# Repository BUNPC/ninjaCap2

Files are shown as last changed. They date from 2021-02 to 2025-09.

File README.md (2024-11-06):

# ninjaCap2 Repo: BRIEF DESCRIPTION
This repository contains the complete framework necessary to generate ninjaCaps. 
This help file explains how to set up and run the ninjacap code using matlab and the blender-python integration. 
Last major version: Feb 2021.

Inputs to this framework are
1. a "probe.SD" file that describes the geometrical setup (as documented in the Homer3 / AtlasViewer toolbox)
1. the desired headcircumference in cm.

Outputs of this code are four .stl files for 3D printing with ninjaflex.

# HOW TO SET EVERYTHING UP

## 1. Install Matlab and the AtlasViewer (Homer3) toolbox for Matlab
The latest Matlab version that the ninjaCap code was successfully tested with is R2019b.
Install the latest version of AtlasViewer and Homer3 (sourcecode, not the executable) for Matlab. You can get them here:	https://github.com/BUNPC/AtlasViewer
https://github.com/BUNPC/Homer3
Don't forget to install the toolbox by running "setpaths" (see AtlasViewer/Homer3 documentation).

## 2. Get the latest version of ninjaCap2 code
you are already here: make a local copy of this repository (https://github.com/neuluce/ninjaCap2).

## 3. Install Blender 2.82 64Bit 
Please note that the ninjacap2 python script may or may not be compatible with older/other versions, 
as blender python commands might be subject to changes over time.
You can get it here:		https://www.blender.org/download/releases/2-82/

## 4. Add necessary Python modules to Blender's Python
Blender uses its own Python. Blender 2.80 upwards uses Python 3.7.
For this reason, you need to install necessary modules (scipy) explicitly into Blender's Python.
If you have your own Python distribution + modules such as Anaconda installed,
blender's Python will not natively find those modules. 
If you manage modules with pip, make sure they are installed into Blender's Python!
In the instructions below, < > defines commands to run in the console and
paths are example paths that need to be adapted to the directories in your installation.
1. Start your Python CMD shell (e.g. Anaconda Prompt) or the Windows CMD console as *administrator*
1. move to the blender\python folder, (e.g. C:\Program Files\Blender Foundation\Blender\2.82\python\bin)
1. from this folder, run *<python -m ensurepip>*. This will link and install pip for python module management. Please note that Blender 2.81 and following versions might not need you to run the ensurepip command. If you get an error when running this command in version(s) 2.81+ just skip this step.
1. update pip and pip wheel by running *<python -m pip install --upgrade pip>* and
	*<python -m pip install --upgrade pip setuptools wheel>*
1. install the **scipy module** using pip. specify the target folder (--target), otherwise the modules might end up in your
	OS python folders and will not be found by Blender. E.g. *<	python -m pip install scipy --target="C:\Program Files\Blender Foundation\Blender\2.80\python\lib">* 
  (adapt directory to your folder structure accordingly).

# PREPARING FILES FOR A CAP BUILD

## 1. Create your "probe.SD" using the newest AtlasViewer GUI. 
Follow the typical process to generate a probe with the AtlasViewer SDgui. Then, for each source, detector AND dummy optode, select the Grommet Type of that optode. The Grommet Type is an identifier that is used in the cap generation to place the desired element (holder, grommet, …) at the position of the corresponding optode. A brief instruction and list of currently supported grommets/holders, including their IDs, is provided [here](https://github.com/neuluce/ninjaCap/blob/master/docu/grommet_lookup.pdf). Selecting the type “#NONE” will skip the placement of a holder/ an element for this optode. You can assign any Grommet Type identifier to any optode (source, detector, and dummy optodes)!

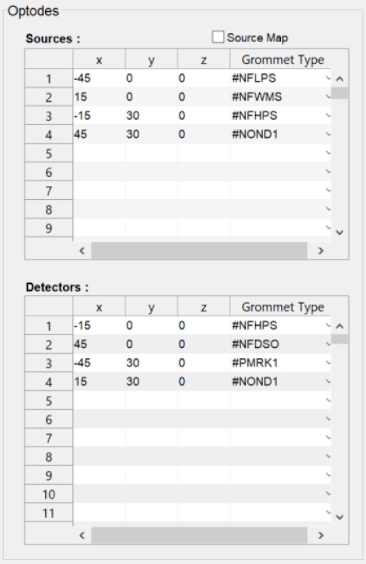
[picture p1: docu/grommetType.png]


Please note for Short Separation (SS) channels: Depending on the type of grommet you choose, short separation channels (holes for a SS fiber) are typically already included. In your SD probe layout, you might have added dedicated SS optodes. If you did, just give those a “#NONE” ID to skip the placement of a dedicated element at the SS optode location.

Please make sure you follow the keep out guidelines shown [here](https://github.com/neuluce/ninjaCap/blob/master/docu/guidelines_keepOutRegions): If you place grommets in the keep out region, they will overlap with the ear slits.
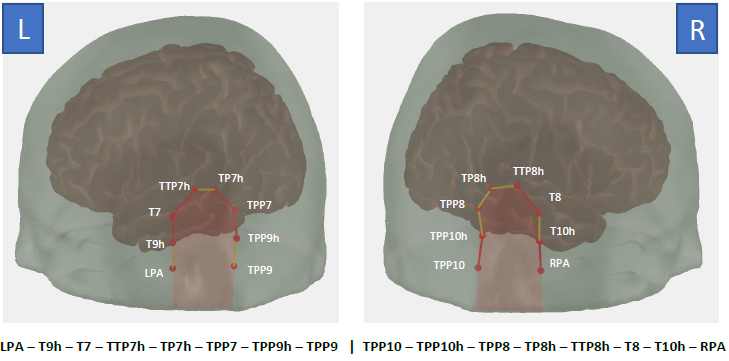
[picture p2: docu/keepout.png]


# HOW TO BUILD A CAP 

## 1. Provide all relevant files:
1. place the "probe.SD" file in a new directory.
1. the following **optional** steps are available, but are not necessary by default:
    1. (optional) provide your own 'atlasViewer.mat' headmodel in the root '.../ninjaCap/' directory
    1. (optional) provide your custom side outline .svg file in the '.../ninjaCap/svg/' directory. -> change the filename in 'ninjaCap/matfun/cap.m' accordingly, if you did not use the default names 'side_piece1.svg' and 'side_piece2.svg'.
    1. (optional, advanced) provide your custom .STL elements to be placed with corresponding grommet IDs. These elements can be grommets, straps, cases, anything. Place them in '.../ninjaCap/stl/elements/<identifier>/'. For this to work, you need to follow the ID-/file-/folder- naming conventions outlined [here](https://github.com/neuluce/ninjaCap/blob/master/docu/grommet_lookup.pdf).
	
## 2. Generate the ninjaCap 
1. Open matlab, go to AtlasViewer directory and add AtlasViewer directory to matlab path by running the command 'setpaths' in the matlab command line. 

2. Go to ninjaCap2 directory and add ninjaCap2 directory to matlab path by running the command 'addpath(genpath('.'))' in the matlab command line.

3. Now go to the "probe.SD" directory and run the function '* generateNinjaCap.m*'. The only argument for this function is the desired head circumference in cm. To generate a cap with 56cm headcircumference, run ' generateNinjaCap(56)'. If you do not provide an argument, 56cm is assumed per default. Watch your cap being built. By the end of the process, matlab open a Blender3D workspace.

4. In the Blender workspace, the python script 'nynja_blender_exec.py' (ninjaCap root directory) should already be loaded per default on the right hand side. If for any case it isnt or you have your own Blender workspace, open the script window and load the script. Run the script by pressing ALT+P or clicking on 'Text -> Run Script' in the script window.

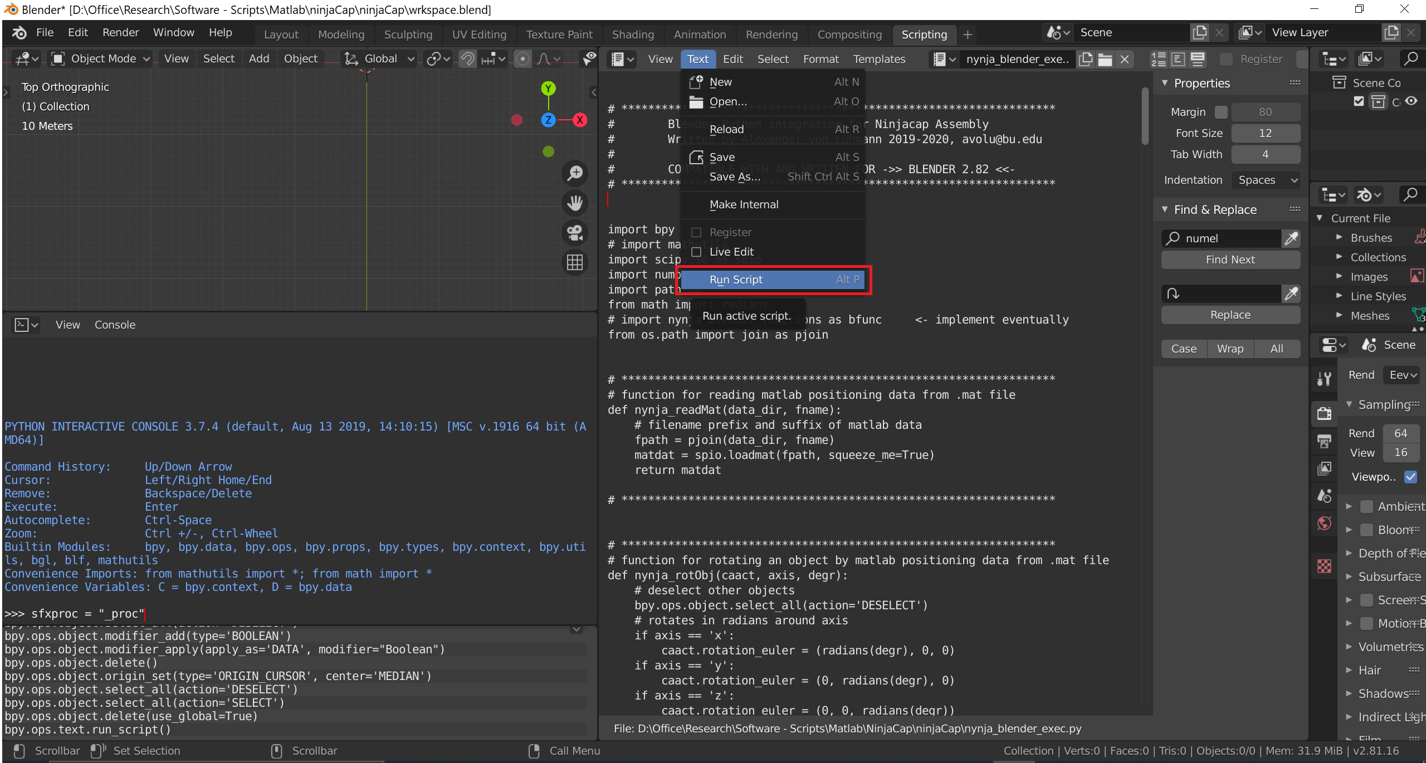
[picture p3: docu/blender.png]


When blender has done its work, close it. This will also terminate the running matlab script.

## 3. Get and print the ninjaCap files
The fully generated and assembled ninjaCap panels are saved in the '.../ninjaCap2/print/' subdirectory.
You should find four .STL files there: 'sideLeft_proc.STL', 'sideRight_proc.STL', 'top1_proc.STL' and 'top2_proc_STL'.
These files can now be 3D printed. For this, use ninjaflex material with the CURA LulzBot Taz 6 Aerostruder and the printing profile 'ninjaCap_profile.curaprofile' that is also provided in the '.../ninjaCap2/print/' subdirectory.
If you want to view the files before moving on to the 3D printing step, you can open them with any STL viewer, such as for example [Meshlab](https://sourceforge.net/projects/meshlab/).

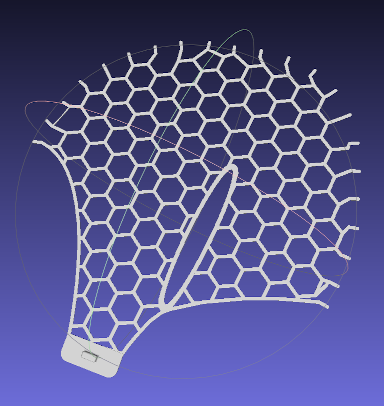
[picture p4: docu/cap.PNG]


## 4. Finish the cap
With all the panels printed, you now need to assemble the cap, e.g. with an ultrasonic welder. Done.

# DIRECTORY AND FILE STRUCTURE
The ninjaCap2 repository has all main scripts and workspaces that need to be executed in the root directory. The subdirectories provide documentation, auxiliary functions, templates, user inputs, generated files, and so forth. This structure is documented in the following:

* /docu/ - contains images and grommet ID manual and documentation
* /extfun/ - contains external matlab scripts, e.g. from matlab central, including the corresponding license files
* /fw/ - a default AtlasViewer directory (**ignore**)
* /imagerecon/ - a default AtlasViewer directory (**ignore**)
* /scripts/ - contains all ninjaCapw matlab scripts and functions called by 'generateNinjaCap.m' and its subroutines.
* /print/ - contains the results of the ninjaCap generation process. You find your .STL files for 3D printing, and the 3D printing profile in here.
* /stl/ - contains (subfolders with) the cap elements that are generated by the matlab routines, as well as element templates (grommets, chinstraps, etc..). The Blender Python script assembles the cap using these elements.
* /svg/ - contains .svg files for the outline of the sidepieces. 
* /template/ - contains templates for the projection of 3D AtlasViewer probe coordinates relative to the EEG 10-10 system onto 2D cap panels.
* / - contains the necessary files for cap generation that the user needs to provide: 'probe.SD'.

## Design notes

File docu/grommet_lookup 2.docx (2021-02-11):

# Preparing files for a ninjaCap build

Inputs to our ninjaCap framework are

1. a "probe.SD" file that describes the geometrical setup (as documented in the Homer2 toolbox) and the grommet types to be used. NOTE: For this you need the latest version of the AtlasViewer GUI (May 2020 or newer)
2. the desired headcircumference in cm.

Outputs of this code are four .stl files for 3D printing with ninjaflex.

## Create your "probe.SD" using the the SDgui of the latest version of AtlasViewer (May 2020 or newer) that you can find here:

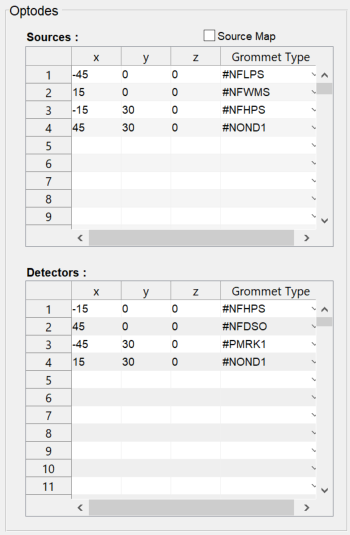
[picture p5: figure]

https://github.com/BUNPC/AtlasViewer

For each source, detector AND dummy optode, select the Grommet Type of that optode. The Grommet Type is an identifier that is used in the cap generation to place the desired element (holder, grommet, …) at the position of the corresponding optode. The available types of grommets and their corresponding identifiers are given in the table on the next page. Selecting the type “#NONE” will skip the placement of an element for this optode. You can assign any Grommet Type identifier to any optode (source, detector, and dummy optodes)!

Please note for Short Separation (SS) Measurements: Depending on the type of grommet you choose, short separation channels (holes for a SS fiber) are typically already included. In your SD probe layout, you might have added dedicated SS optodes. If you did, just give those a “#NONE” ID to skip the placement of a dedicated element at the SS optode location.

Save that configuration under the name "probe" with the native ".SD" file extension under …\ninjaCap\userinput\probe.SD.

If you want to add your own (custom) Grommet Type:

STL files for these elements are placed under
…/ninjaCap/stl/elements/<identifier>/…

where <identifier> is the folder name identical to the defined string ID. Files within are always “grommet.stl” and “grommetComplement.stl”, where “grommet” is the element to be placed, and “grommetComplement” is the keep out geometry used to create corresponding holes/spaces in the panel grids. This compliment must be the same size as the needed gap in the pattern of the panel grids for the hole produced by the grommet. These “grommets” can have any geometry and can also be elements that are not “grommets” after all. If your grommet ID is not available in AtlasViewer, you can select any type and manually change them to your new custom ID by manually opening the SD file in matlab and changing the entries in the following three fields of SD struct: ‘SrcGrommetType’, ‘DetGrommetType’ and ‘DummyGrommetType’. When saving the STL for a new grommet you must ensure that the grommet is aligned on the X-Y plane as it’s bottom and the origin point for both the grommet and the compliment must be in the center of their hole for the optode to ensure correct grommet placement on the ninjaCap.

Identifier | Info | Image | Dimensions

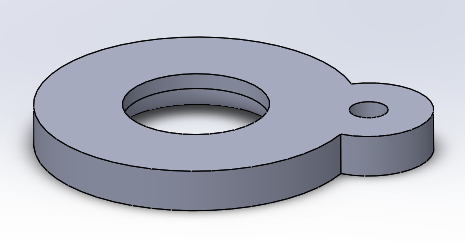
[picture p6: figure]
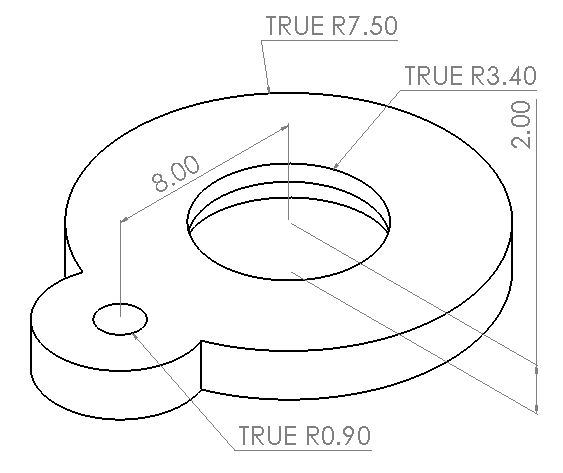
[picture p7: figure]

#NFLPS | NIRS: Fiber-based optode holder (CW6 fibers) with Low Profile and single Short-separation hole

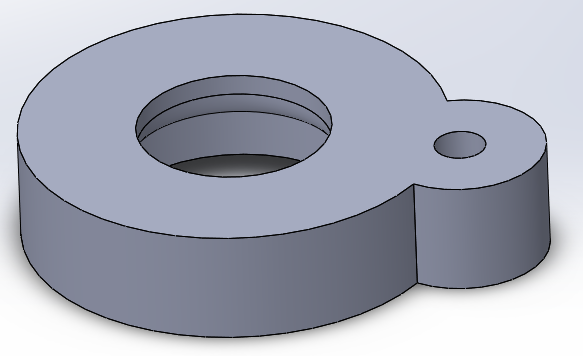
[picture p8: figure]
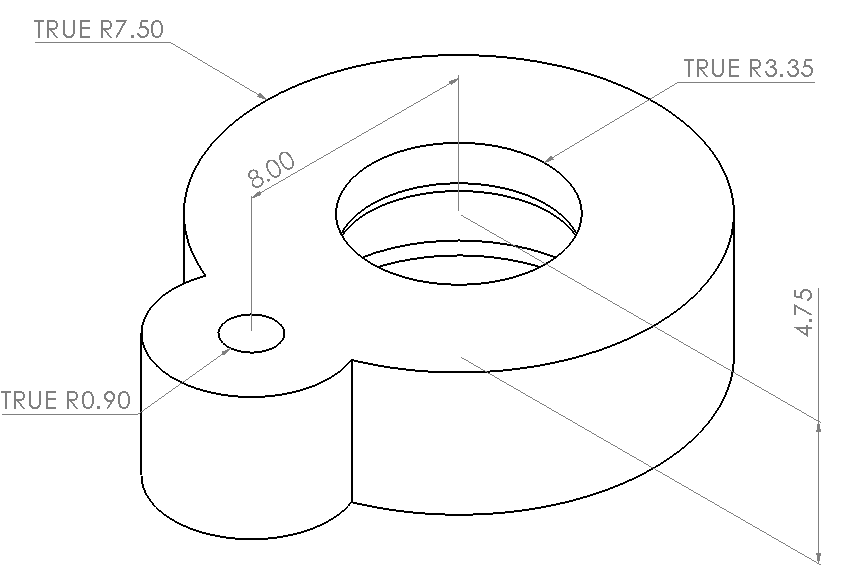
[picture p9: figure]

#NFHPS | NIRS: Fiber-based optode holder (CW6 fibers) with High Profile and single Short-separation hole

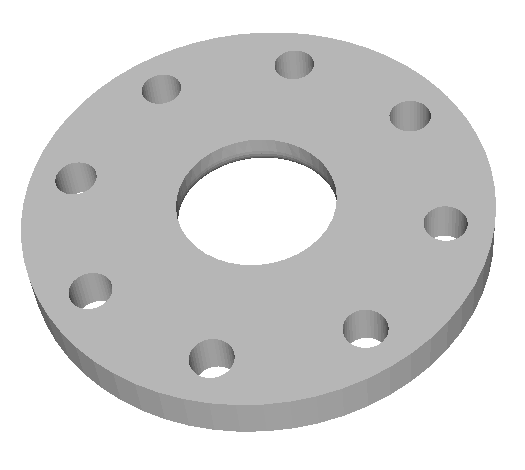
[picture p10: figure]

#NFWMS | NIRS: Fiber-based Wide optode holder (CW6 fibers) with Multiple Short-separation holes | | Inner radius: 03.4 mm Outer radius: 08.0 mm Height: 02.0 mm SS Distance: 08.0 mm SS radius: 0.90 mm

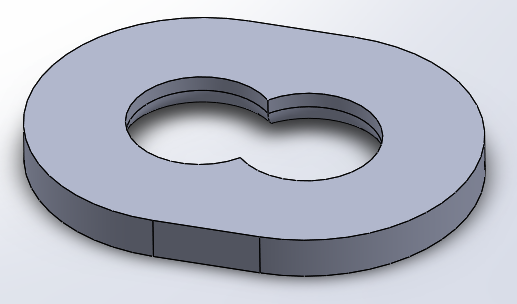
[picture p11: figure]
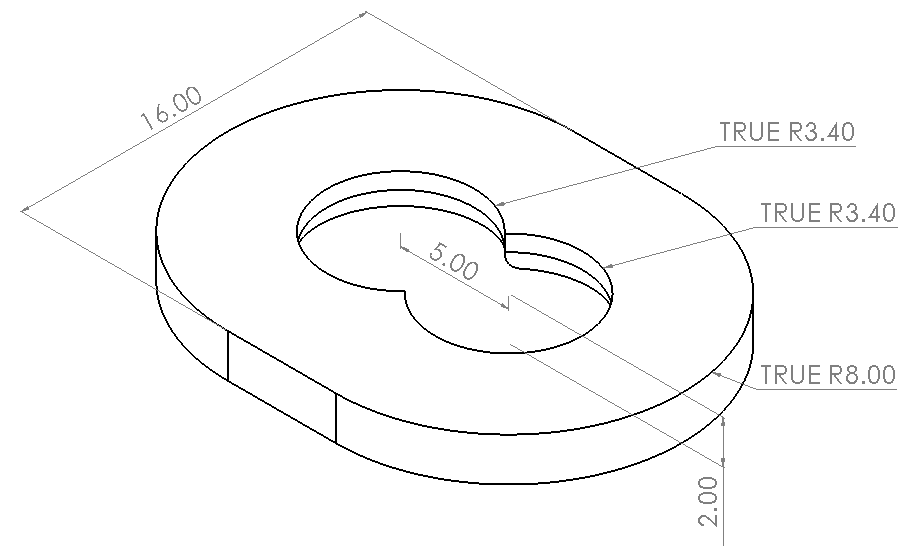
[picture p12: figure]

#NFDSO | NIRS: Fiber-based Dual Ss Optode holder

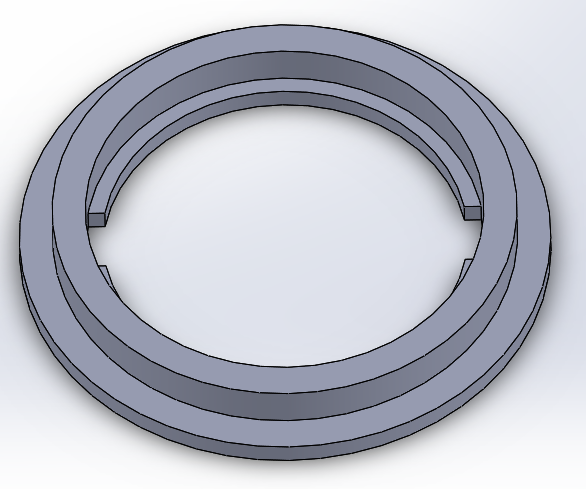
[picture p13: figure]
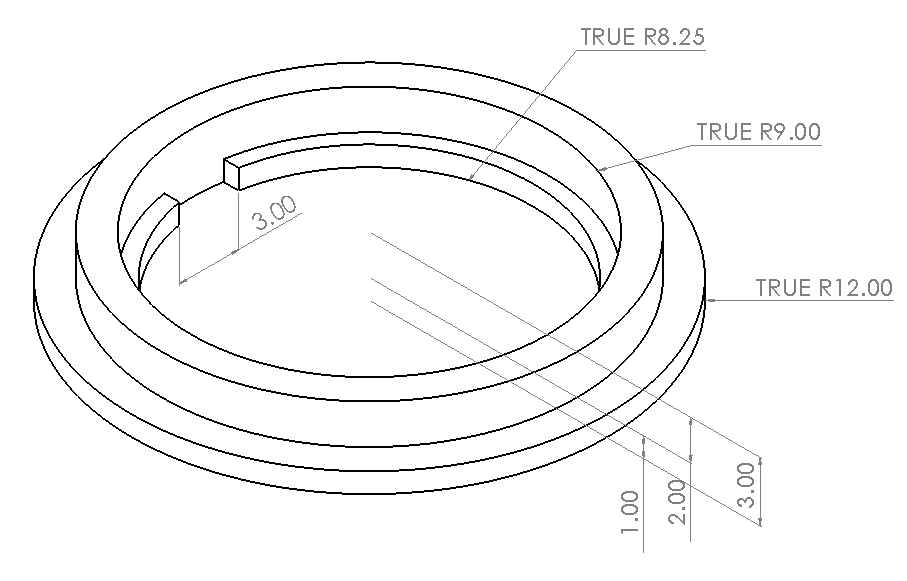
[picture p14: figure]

#NOND1 | NIRS: Open fNIRS Dual optode holder for optodes in printed case

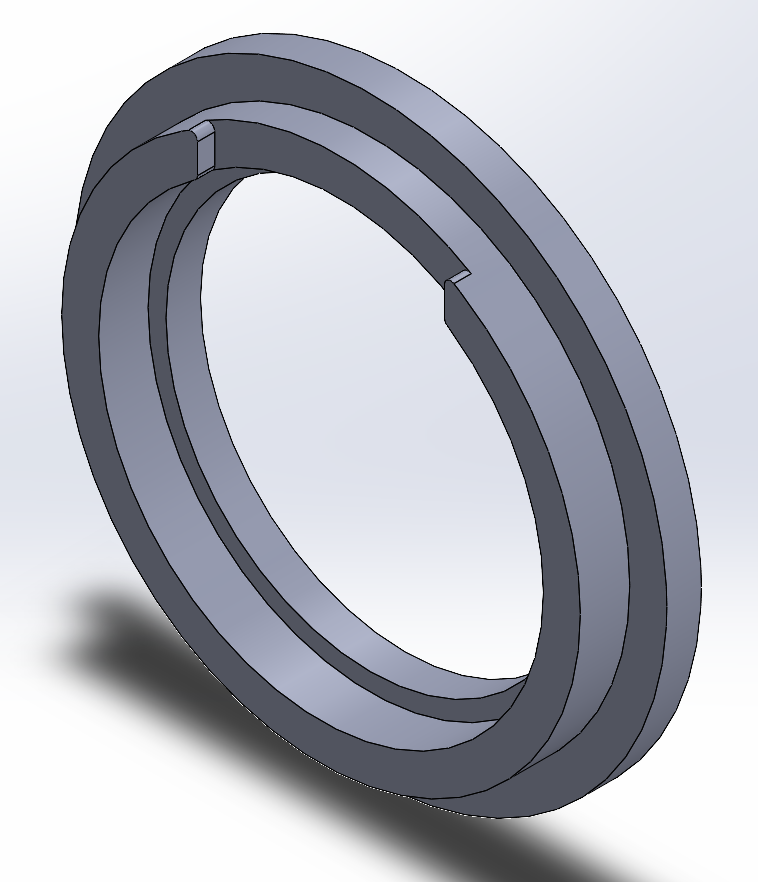
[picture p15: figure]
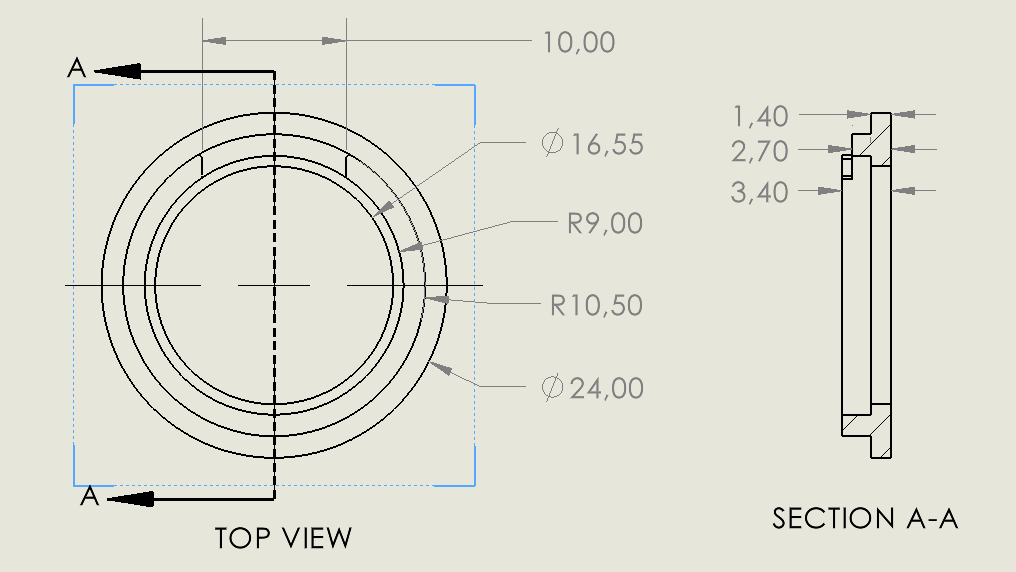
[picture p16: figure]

#NOND2 | NIRS: Open fNIRS dual optode holder for optodes in printed cases Rev AB and later

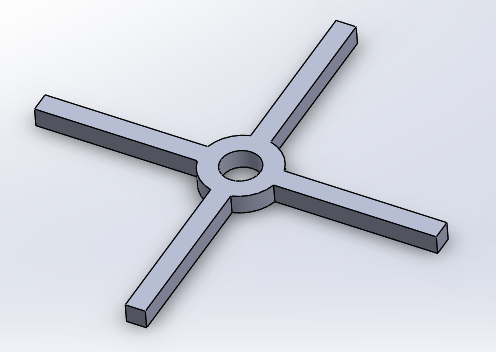
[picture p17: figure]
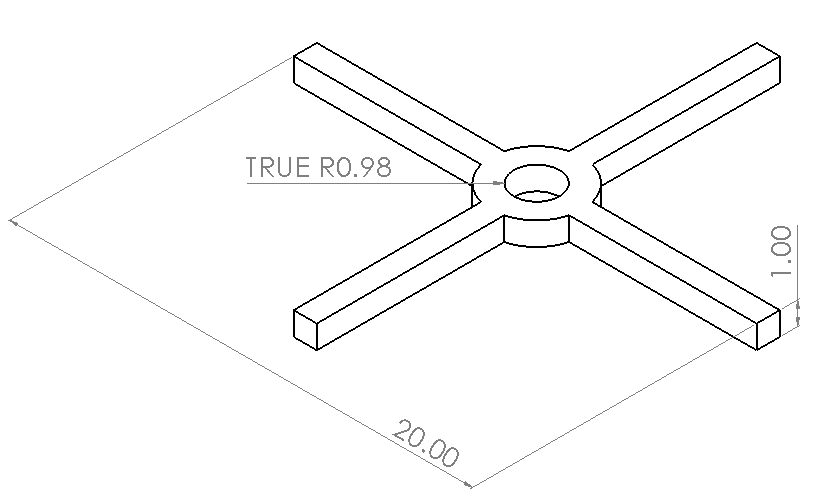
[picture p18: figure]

#PMRK1 | Position MaRKer in small cross shape, symmetric

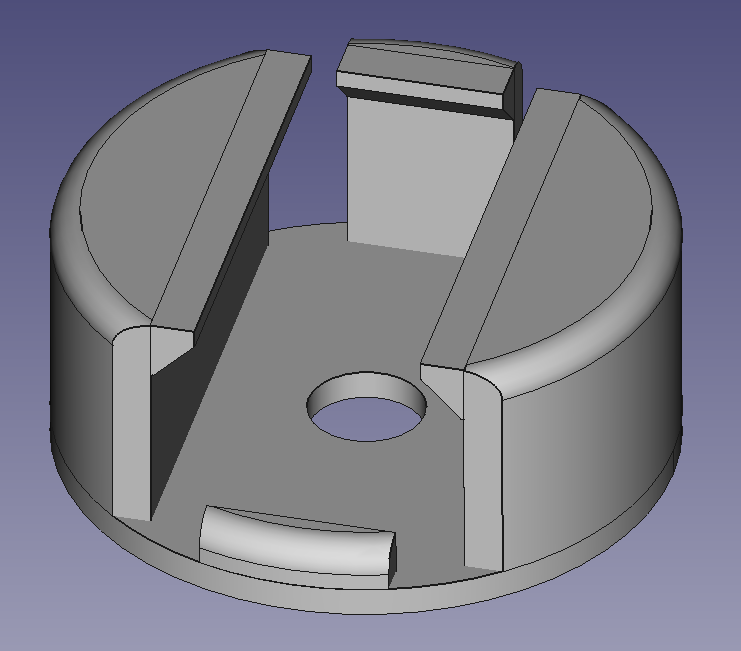
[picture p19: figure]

#ACHLD | ninjaNIRS Accelerometer HoLDer | | 21 mm diameter 10 mm height

Continued on the next page…

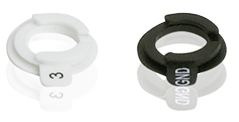
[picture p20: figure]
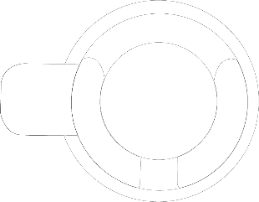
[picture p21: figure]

#EBPAS (currently N/A) | EEG electrode holder from Brain Products: ActiCap Snap

#EECEH (currently N/A) | EEG Easy Cap Electrode Holder: Ring for commercial electrode holders | Tbd | Tbd

#NONE | Dummy Optode, nothing placed | None | None

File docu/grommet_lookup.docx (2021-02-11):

# Preparing files for a ninjaCap build

Inputs to our ninjaCap framework are

1. a "probe.SD" file that describes the geometrical setup (as documented in the Homer2 toolbox) and the grommet types to be used. NOTE: For this you need the latest version of the AtlasViewer GUI (May 2020 or newer)
2. the desired headcircumference in cm.

Outputs of this code are four .stl files for 3D printing with ninjaflex.

## Create your "probe.SD" using the the SDgui of the latest version of AtlasViewer (May 2020 or newer) that you can find here:


https://github.com/BUNPC/AtlasViewer

For each source, detector AND dummy optode, select the Grommet Type of that optode. The Grommet Type is an identifier that is used in the cap generation to place the desired element (holder, grommet, …) at the position of the corresponding optode. The available types of grommets and their corresponding identifiers are given in the table on the next page. Selecting the type “#NONE” will skip the placement of an element for this optode. You can assign any Grommet Type identifier to any optode (source, detector, and dummy optodes)!

Please note for Short Separation (SS) Measurements: Depending on the type of grommet you choose, short separation channels (holes for a SS fiber) are typically already included. In your SD probe layout, you might have added dedicated SS optodes. If you did, just give those a “#NONE” ID to skip the placement of a dedicated element at the SS optode location.

Save that configuration under the name "probe" with the native ".SD" file extension under …\ninjaCap\userinput\probe.SD.

If you want to add your own (custom) Grommet Type:

When saving the STL for a new grommet you must ensure that the grommet is aligned on the X-Y plane as the bottom surface of the grommet and the origin point for both the grommet and the compliment must be the center of the object for the optode to ensure correct grommet placement on the ninjaCap. To ensure this is done correctly using Solidworks, when exporting the STL from the solidworks part under options select options:

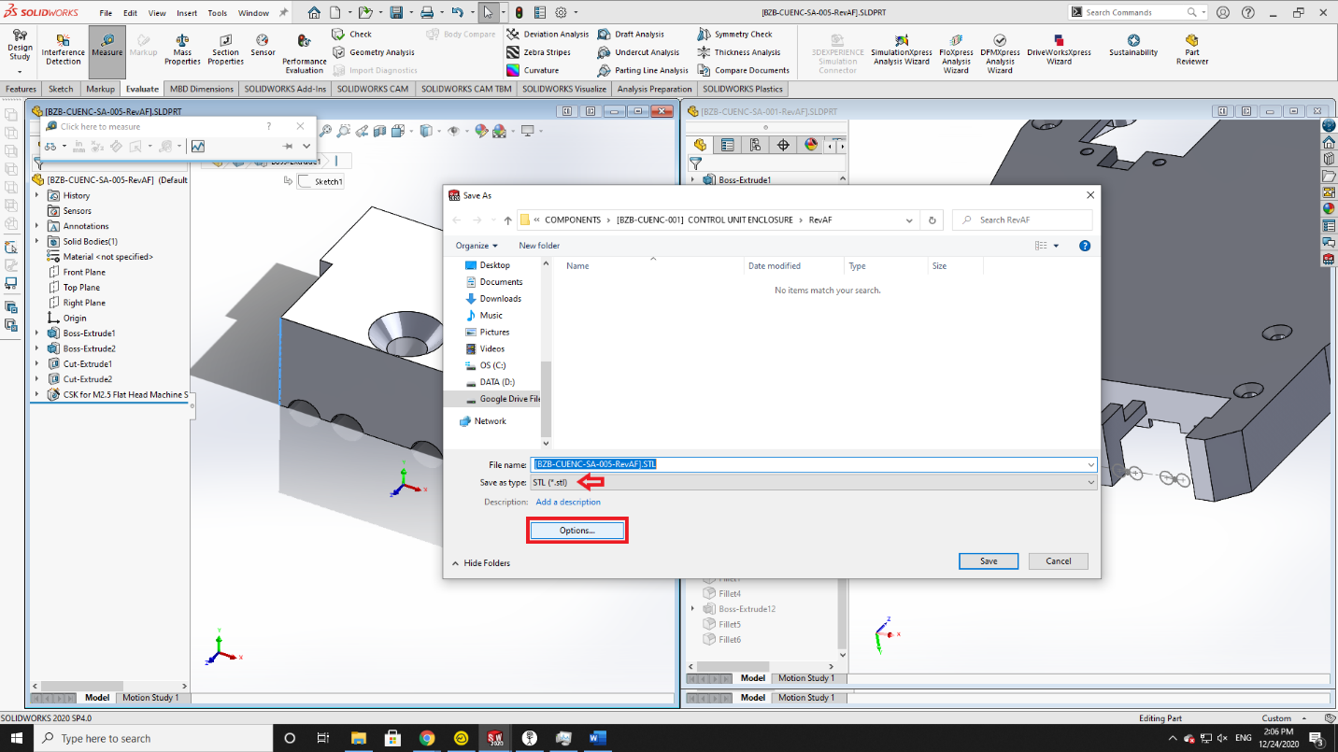
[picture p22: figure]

After pressing options you will be brought to a menu shown below, select the highlighted option and click ok then save the grommet/complement file.

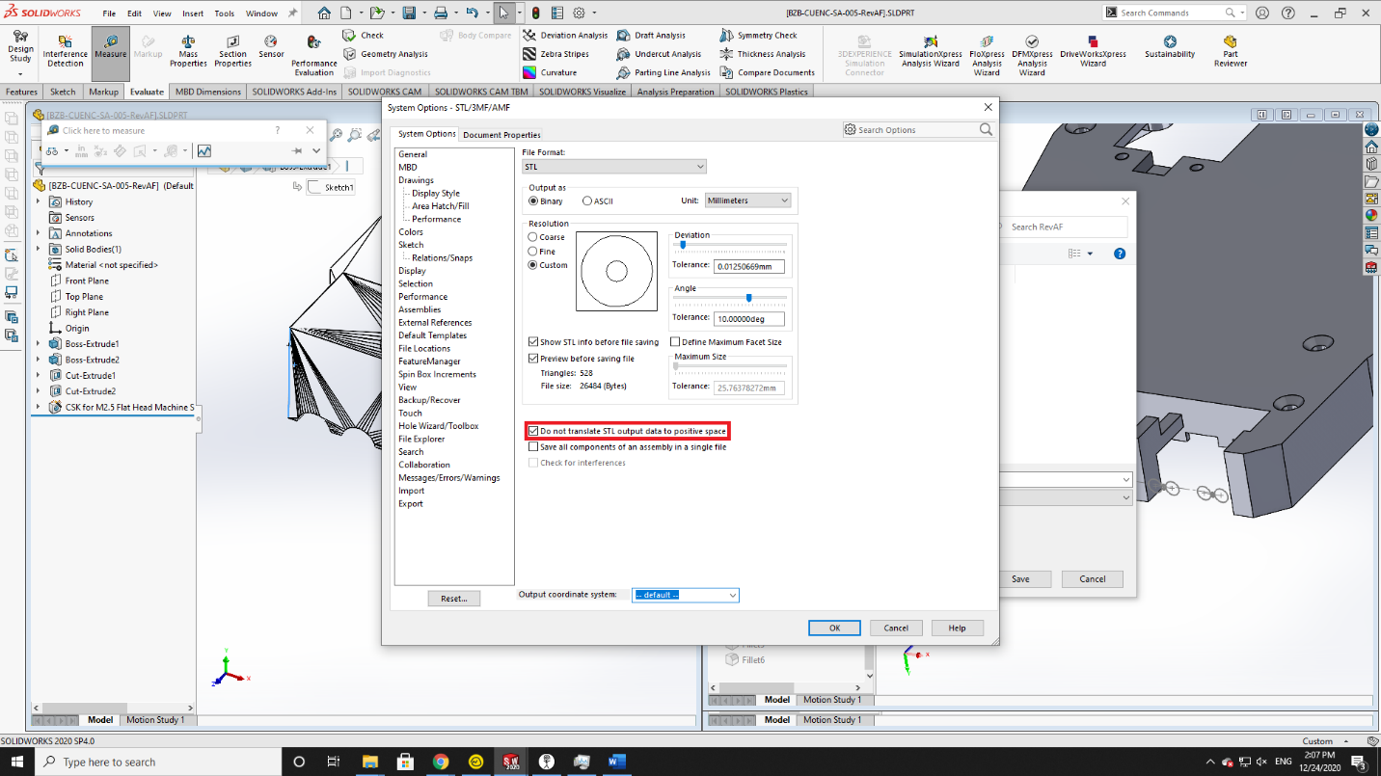
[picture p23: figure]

STL files for these elements are placed under
…/ninjaCap/stl/elements/<identifier>/…

where <identifier> is the folder name identical to the defined string ID. Files within are always “grommet.stl” and “grommetComplement.stl”, where “grommet” is the element to be placed, and “grommetComplement” is the keep out geometry used to create corresponding holes/spaces in the panel grids. This compliment must be the same size as the needed gap in the pattern of the panel grids for the hole produced by the grommet. These “grommets” can have any geometry and can also be elements that are not “grommets” after all. If your grommet ID is not available in AtlasViewer, you can select any type and manually change them to your new custom ID by manually opening the SD file in matlab and changing the entries in the following three fields of SD struct: ‘SrcGrommetType’, ‘DetGrommetType’ and ‘DummyGrommetType’.

Identifier | Info | Image | Dimensions


#NFLPS | NIRS: Fiber-based optode holder (CW6 fibers) with Low Profile and single Short-separation hole


#NFHPS | NIRS: Fiber-based optode holder (CW6 fibers) with High Profile and single Short-separation hole


#NFWMS | NIRS: Fiber-based Wide optode holder (CW6 fibers) with Multiple Short-separation holes | | Inner radius: 03.4 mm Outer radius: 08.0 mm Height: 02.0 mm SS Distance: 08.0 mm SS radius: 0.90 mm


#NFDSO | NIRS: Fiber-based Dual Ss Optode holder


#NOND1 | NIRS: Open fNIRS Dual optode holder for optodes in printed case


#NOND2 | NIRS: Open fNIRS dual optode holder for optodes in printed cases Rev AB through Rev AD

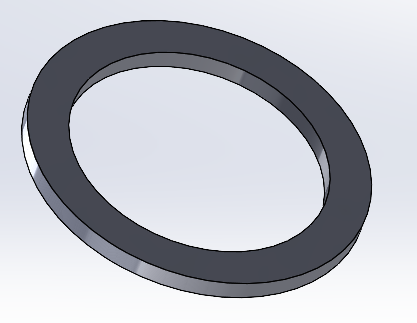
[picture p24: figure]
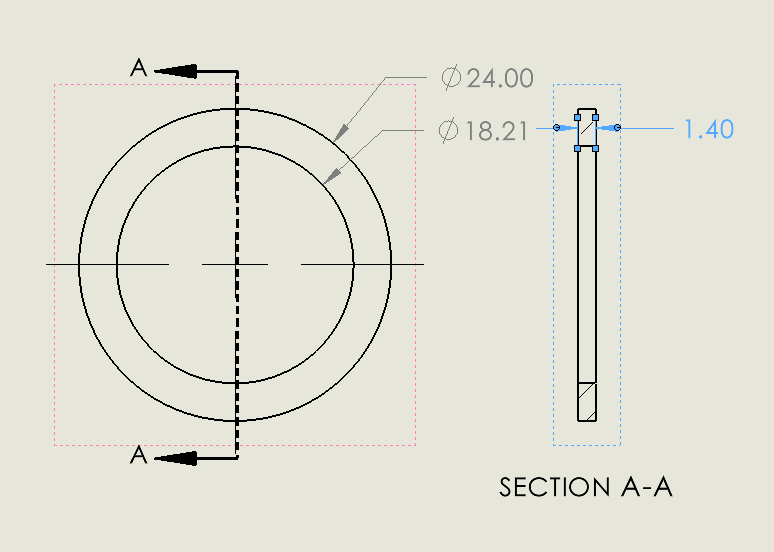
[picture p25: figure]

#NOND3 | NIRS: Open fNIRS dual optode holder for optodes in printed cases Rev AE and later


#PMRK1 | Position MaRKer in small cross shape, symmetric


#ACHLD | ninjaNIRS Accelerometer HoLDer | | 21 mm diameter 10 mm height

Continued on the next page…


#EBPAS (currently N/A) | EEG electrode holder from Brain Products: ActiCap Snap

#EECEH (currently N/A) | EEG Easy Cap Electrode Holder: Ring for commercial electrode holders | Tbd | Tbd

#NONE | Dummy Optode, nothing placed | None | None

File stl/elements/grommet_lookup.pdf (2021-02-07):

Identifier | Info | Image | Dimensions
#NFLPS | NIRS: Fiber-based optode holder (CW6 fibers) with Low Profile and single Short-separation hole

#NFHPS | NIRS: Fiber-based optode holder (CW6 fibers) with High Profile and single Short-separation hole

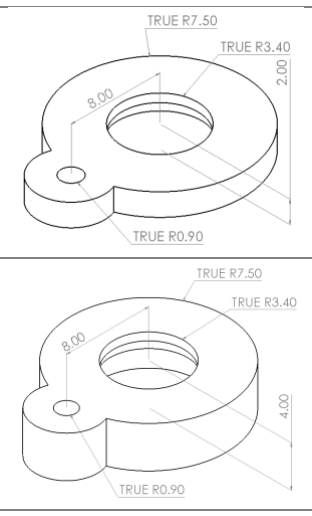
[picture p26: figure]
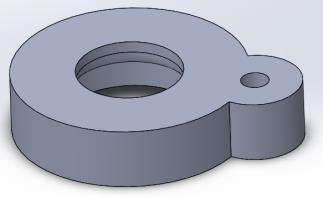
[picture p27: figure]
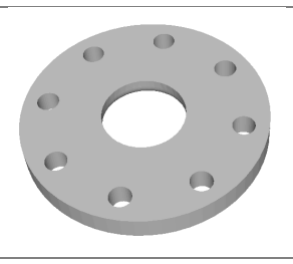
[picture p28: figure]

#NFWMS | NIRS: Fiber-based Wide optode holder (CW6 fibers) with Multiple Short-separation holes | | Inner radius: 03.4 mm Outer radius: 08.0 mm Height: 02.0 mm SS Distance: 08.0 mm SS radius: 0.90 mm


#NFDSO | NIRS: Fiber-based Dual Ss Optode holder


#NOND1 | NIRS: Open fNIRS Dual optode holder for optodes in printed case


#PMRK1 | Position MaRKer in small cross shape, symmetric

#EBPAS | EEG electrode holder from Brain Products: ActiCap Snap


#EECEH | EEG Easy Cap Electrode Holder: Ring for commercial electrode holders | Tbd | Tbd

#DUMMY | Dummy Optode, nothing placed | None | None

How to provide grommet information:

Supply matlab file “gIDs.mat” with variable “gIDs” together with the AtlasViewer.mat file in the main ninjaCap folder.

“gIDs” is 1 x N matlab cell array of strings, where N is the number of all probes in the AtlasViewer patch including dummy (anchor) optodes. The type of each element to be placed is identified by the string ID from the above table and its index. The index corresponds to the optode number in AtlasViewer.


STL files for the elements are placed under
…/ninjaCap/stl/elements/<identifier>/…

where <identifier> is the folder name identical to the defined string ID. Files within are always “grommet.stl” and “grommetComplement.stl”, where “grommet” is the element to be placed, and “grommetComplement” is the keep out geometry used to create corresponding holes/spaces in the panel grids.

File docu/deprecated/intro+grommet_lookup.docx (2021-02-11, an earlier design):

# ninjaCap: Brief introduction

Inputs to our ninjaCap framework are

1. a "probe.SD" file that describes the geometrical setup (as documented in the Homer2 toolbox)
2. a "gIDs.mat" file that assigns an ID (=type) to each grommet in the probe.
3. the desired headcircumference in cm.

Outputs of this code are four .stl files for 3D printing with ninjaflex.

# PREPARING FILES FOR A CAP BUILD

## 1. Create your "probe.SD" using Homer's AtlasViewer GUI.

Save that configuration under the name "probe" with the native ".SD" file extension. Keep your "probe.SD" for later.

## 2. Create your "gIDs.mat" file

All optodes in your SD probe, be it emitters, detectors, or dummy/anchor optodes, will need to be assigned a grommet identifier ("gID"). These identifiers are 6-character strings, with the first character being a '#', e.g. '#DUMMY'. The ninjaCap code uses these identifiers to place grommets (optode holders) or other elements at the respective position in 3D. A brief instruction and list of currently supported grommets/holders, including their IDs, is provided in the table on the next page. You can also come up with your own unique ID and add the corresponding STL files, following a naming and directory convention, as briefly outlined in the above docu file.

1. If you use Homer2 to generate your probe.SD, you will have to manually generate the gIDs file, which is a 1 x N matlab cell array of strings, where N is the overal number of optodes, including dummy/anchor optodes in your probe. To generate the gIDs.mat file, you can use and adapt the "generate_gIDs_example.m" script in the root ninjaCap directory.
2. If you use Homer3, you will (soon) be able to just assign each optode its gID in the drop down menu of the AtlasViewer probe GUI. The rest is automatically handled. This feature is currently not yet active.

Identifier | Info | Image | Dimensions


#NFLPS | NIRS: Fiber-based optode holder (CW6 fibers) with Low Profile and single Short-separation hole


#NFHPS | NIRS: Fiber-based optode holder (CW6 fibers) with High Profile and single Short-separation hole


#NFWMS | NIRS: Fiber-based Wide optode holder (CW6 fibers) with Multiple Short-separation holes | | Inner radius: 03.4 mm Outer radius: 08.0 mm Height: 02.0 mm SS Distance: 08.0 mm SS radius: 0.90 mm


#NFDSO | NIRS: Fiber-based Dual Ss Optode holder


#NOND1 | NIRS: Open fNIRS Dual optode holder for optodes in printed case


#PMRK1 | Position MaRKer in small cross shape, symmetric


#ACHLD | ninjaNIRS ACcelerometer HoLDer | | 21 mm diameter 10 mm height


#EBPAS (currently N/A) | EEG electrode holder from Brain Products: ActiCap Snap

#EECEH (currently N/A) | EEG Easy Cap Electrode Holder: Ring for commercial electrode holders | Tbd | Tbd

#DUMMY | Dummy Optode, nothing placed | None | None

How to provide grommet information:
Supply matlab file “gIDs.mat” with variable “gIDs” (grommet IDs) together with the AtlasViewer .SD probe file to us (details on how to generate the gIDs.mat file below)
For generating the cap files (internal): provide both files in the main ninjaCap code directory.

“gIDs” is a 1 x N+A matlab cell array of strings, where N+A is the number of all N optodes and A anchor (dummy) optodes in the AtlasViewer SD probe patch. In the gIDs file, any optode labeled as dummy optode is being skipped - no grommet is being placed at that position. The type of each other element to be placed is identified by the string ID from the above table. The cell array’s index corresponds to the optode number in AtlasViewer, see image below.


In the above example the .SD probe consists of 8 optodes (index 1-8) and 4 dummy optodes (index 9-12). Fill each corresponding cell array entry with the desired grommet identifier, and – if you do not want anything placed on the dummy optode positions - fill in #DUMMY in the corresponding elements (here 9-12)

Please note for Short Separation (SS) Measurements: Depending on the type of grommet you choose, short separation channels (holes for a SS fiber) are typically already included. In your SD probe layout, you might have added dedicated SS optodes. If you did, just give those a “#DUMMY” ID and no dedicated grommet will be placed at the SS optode location.

Further cap generation information:

STL files for these elements are placed under
…/ninjaCap/stl/elements/<identifier>/…

where <identifier> is the folder name identical to the defined string ID. Files within are always “grommet.stl” and “grommetComplement.stl”, where “grommet” is the element to be placed, and “grommetComplement” is the keep out geometry used to create corresponding holes/spaces in the panel grids. These “grommets” can have any geometry and can also be elements that are not “grommets” after all.

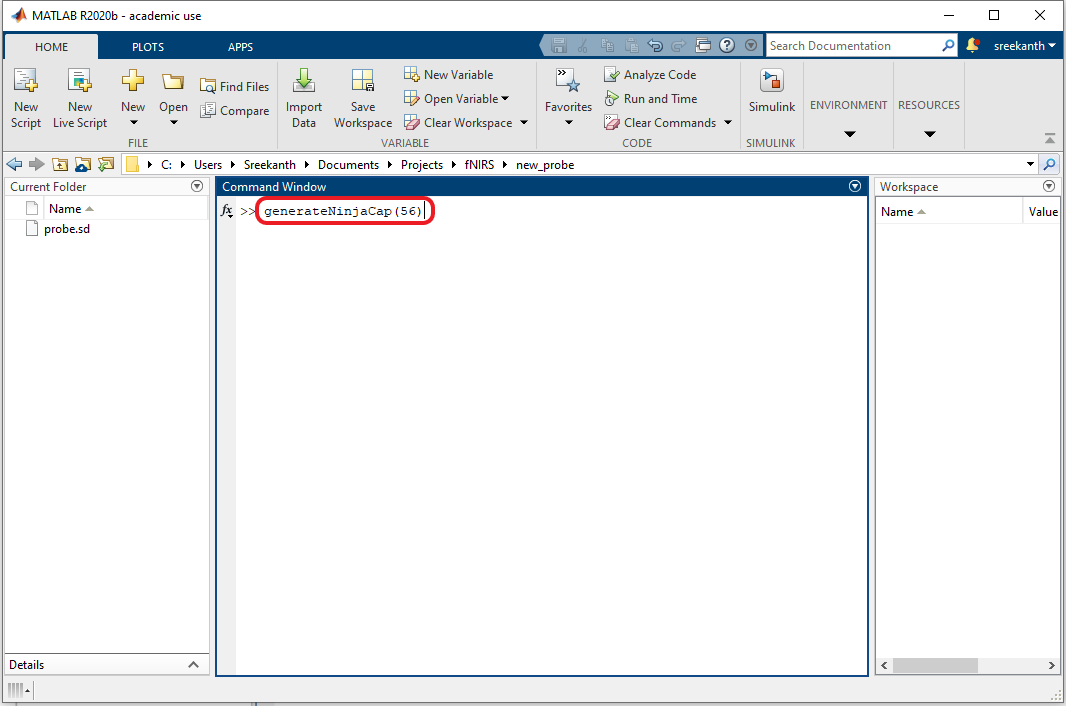
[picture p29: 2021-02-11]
docu/matlab.PNG

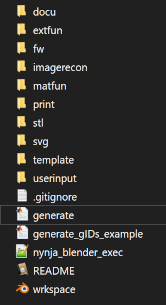
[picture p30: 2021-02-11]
docu/dirstruct.PNG

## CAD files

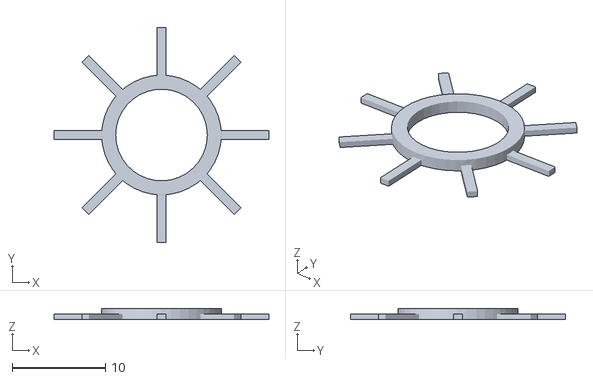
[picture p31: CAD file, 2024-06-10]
stl/elements/#NIRX2/grommet.STL
23.0 x 23.0 x 1.20

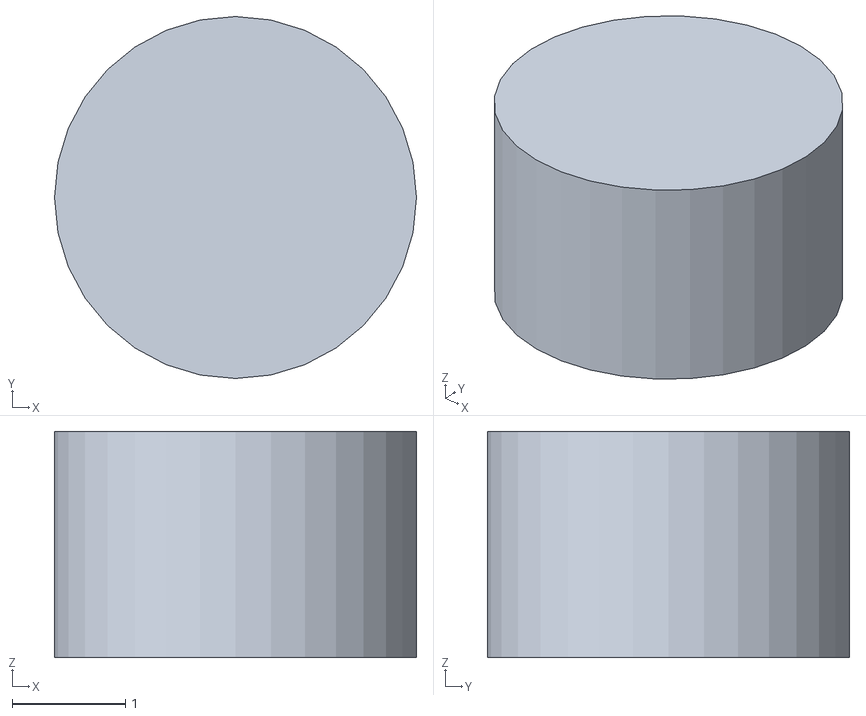
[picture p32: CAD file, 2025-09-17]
stl/elements/#UHD-D/grommetComplement.stl
3.20 x 3.20 x 2.00

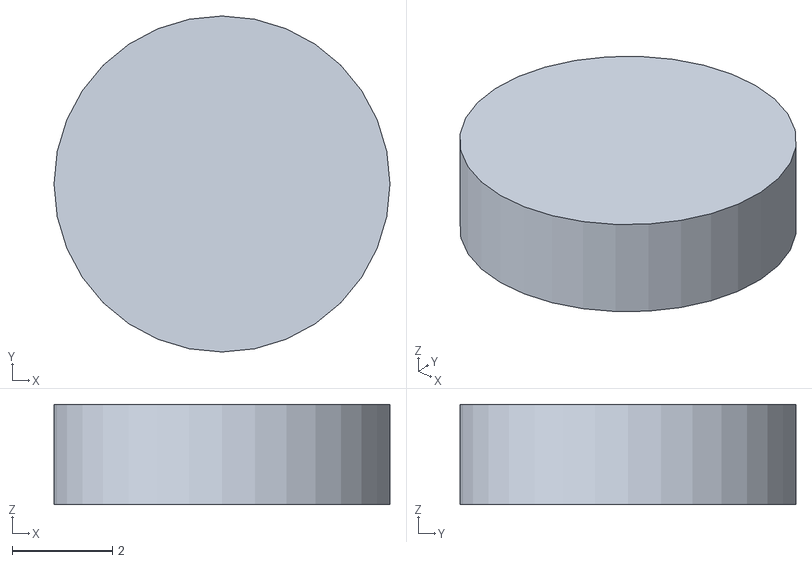
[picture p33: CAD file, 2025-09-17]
stl/elements/#UHD-S/grommetComplement.stl
6.70 x 6.70 x 2.00

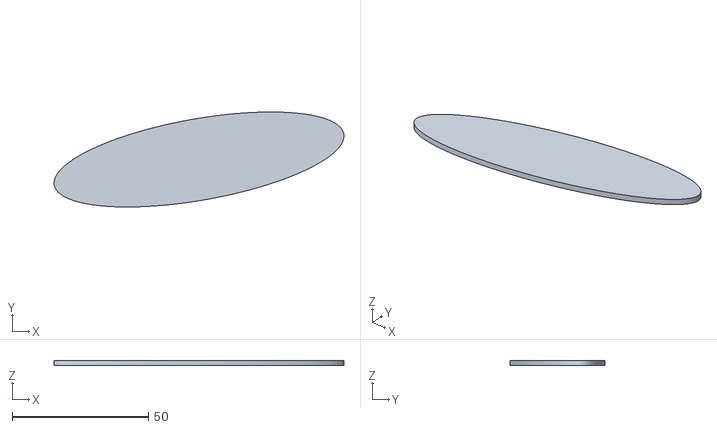
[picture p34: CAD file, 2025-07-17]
stl/elements/earslitComplement_right.stl
106.4 x 34.9 x 2.00

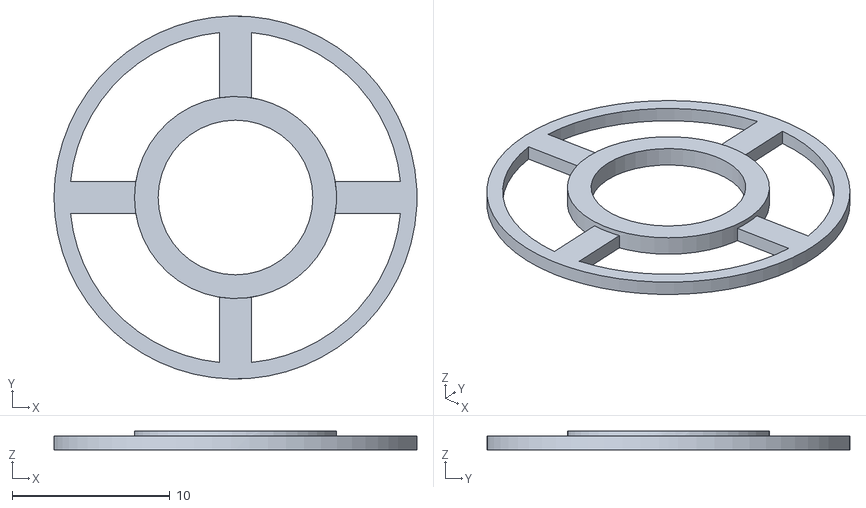
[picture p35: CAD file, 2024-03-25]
stl/elements/#NIRX2/grommet_thiner_outerlayer.STL
23.0 x 23.0 x 1.20

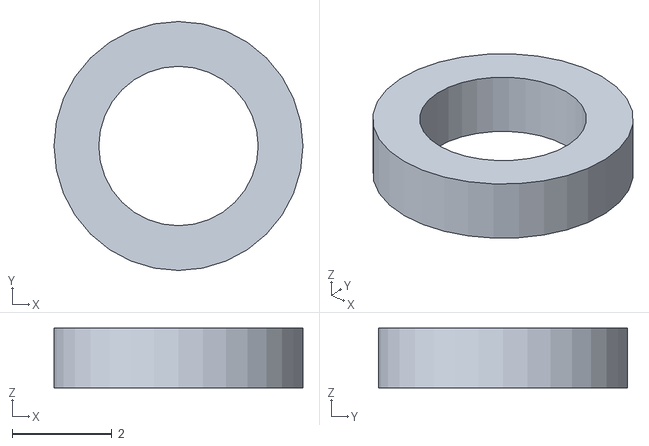
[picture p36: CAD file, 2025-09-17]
stl/elements/#UHD-D/grommet.stl
5.00 x 5.00 x 1.20

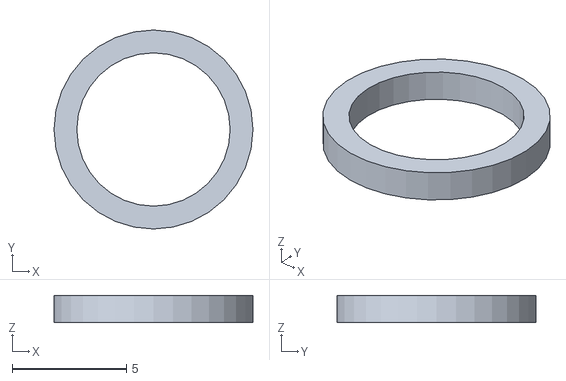
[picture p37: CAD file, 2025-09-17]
stl/elements/#UHD-S/grommet.stl
8.70 x 8.70 x 1.20

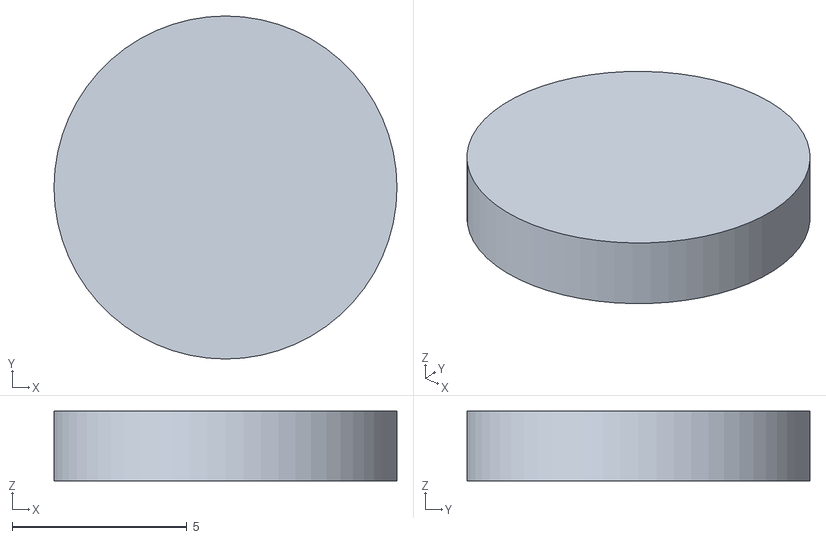
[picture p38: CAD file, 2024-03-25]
stl/elements/#NIRX2/grommetComplement_not_centered.STL
9.80 x 9.80 x 2.00

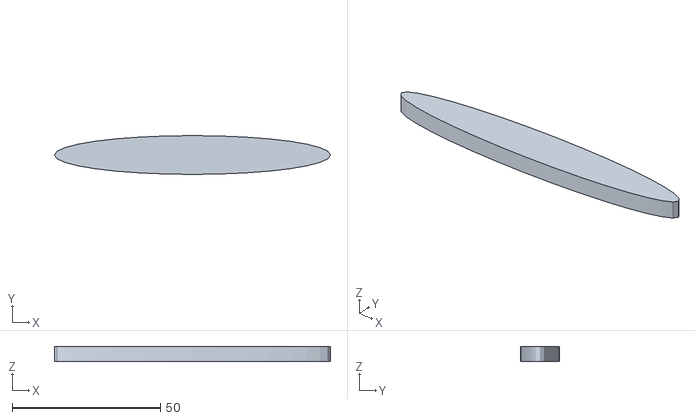
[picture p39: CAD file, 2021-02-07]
stl/elements/earslitComplement.stl
93.0 x 13.1 x 4.90

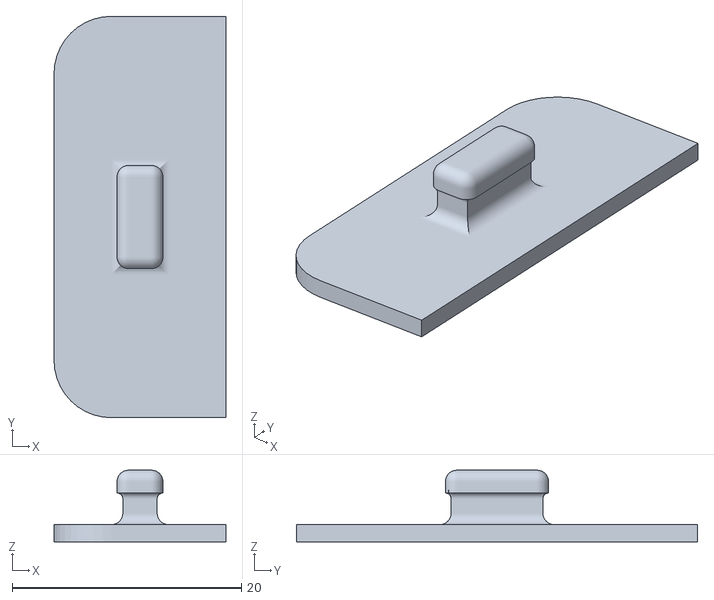
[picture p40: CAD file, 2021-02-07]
stl/elements/chStrap.stl
15.0 x 35.0 x 6.25

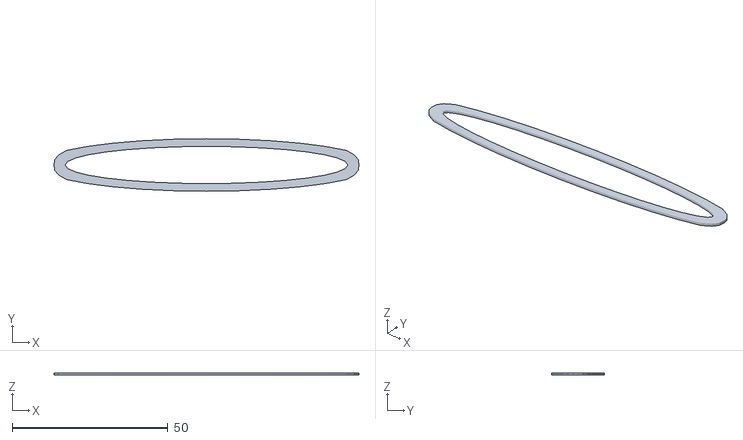
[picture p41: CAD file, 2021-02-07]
stl/elements/earslit.stl
97.9 x 16.9 x 0.77

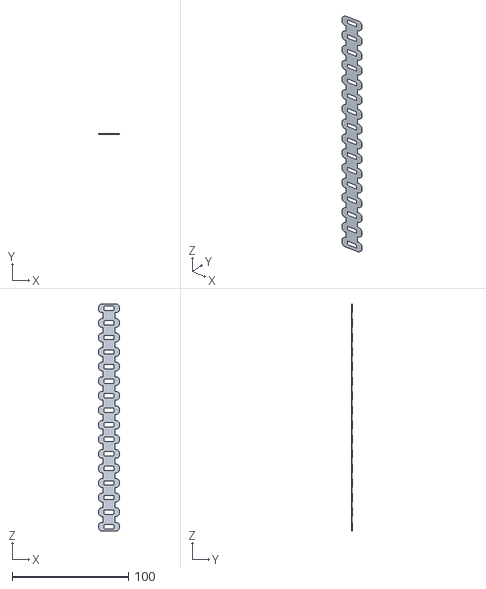
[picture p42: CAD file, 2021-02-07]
stl/elements/chinstrap.STL
18.0 x 1.00 x 195.0

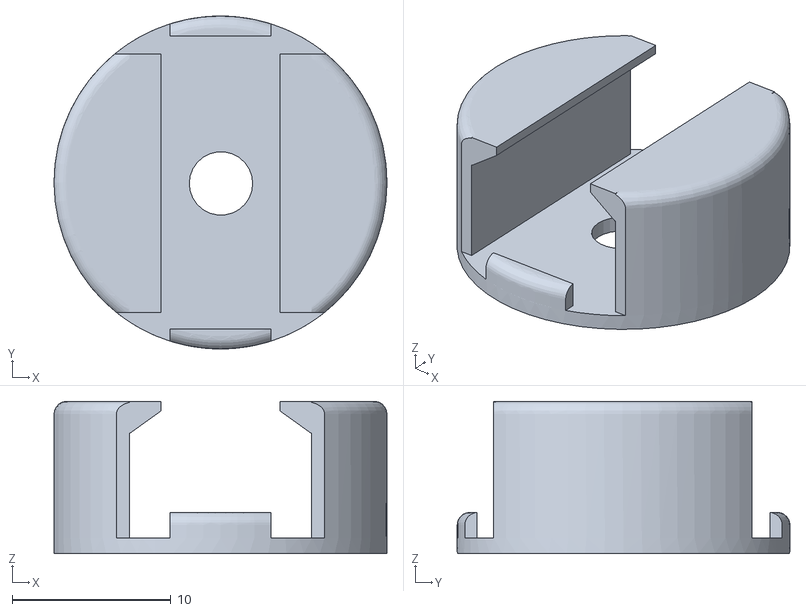
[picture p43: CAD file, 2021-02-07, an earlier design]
stl/elements/#ACHLD/grommet.stl
21.0 x 21.0 x 9.60

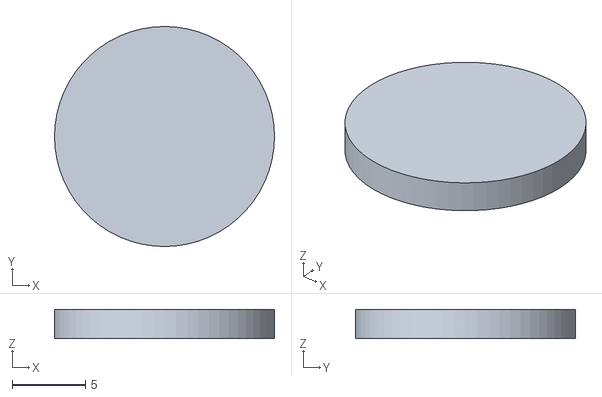
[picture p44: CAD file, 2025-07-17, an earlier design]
stl/elements/#EEG1/grommetComplement.STL
15.0 x 15.0 x 2.00

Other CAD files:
stl/elements/earslitComplement_left.stl
stl/elements/#NIRX2/grommet_not_centered.STL
stl/elements/#NIRX2/grommetComplement.STL
stl/elements/#NFDSO/grommet.STL
stl/elements/#ACHLD/grommetComplement.stl
stl/elements/#EEG1/grommet.STL
stl/elements/#NFDSO/grommetComplement.STL
stl/elements/#NFHPS/grommet.STL
stl/elements/#NFHPS/grommetComplement.STL
stl/elements/#NFLPS/grommet.STL
stl/elements/#NFLPS/grommetComplement.STL
stl/elements/#NFWMS/grommet.STL
stl/elements/#NFWMS/grommetComplement.STL
stl/elements/#NIRX2/grommet_old.STL
stl/elements/#NIRX2_2/grommet.stl
stl/elements/#NIRX2_2/grommetComplement.stl
stl/elements/#NN21A/grommet.stl
stl/elements/#NN21A/grommetComplement.stl
stl/elements/#NOND1/grommet.STL
stl/elements/#NOND1/grommetComplement.STL
stl/elements/#NOND2/grommet.STL
stl/elements/#NOND2/grommetComplement.STL
stl/elements/#NOND3/grommet.stl
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

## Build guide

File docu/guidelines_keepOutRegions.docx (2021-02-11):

ninjaCap: Keep-out regions for ear slit (10-5 choordinates/ anchors)

see also keepOutEar.SD

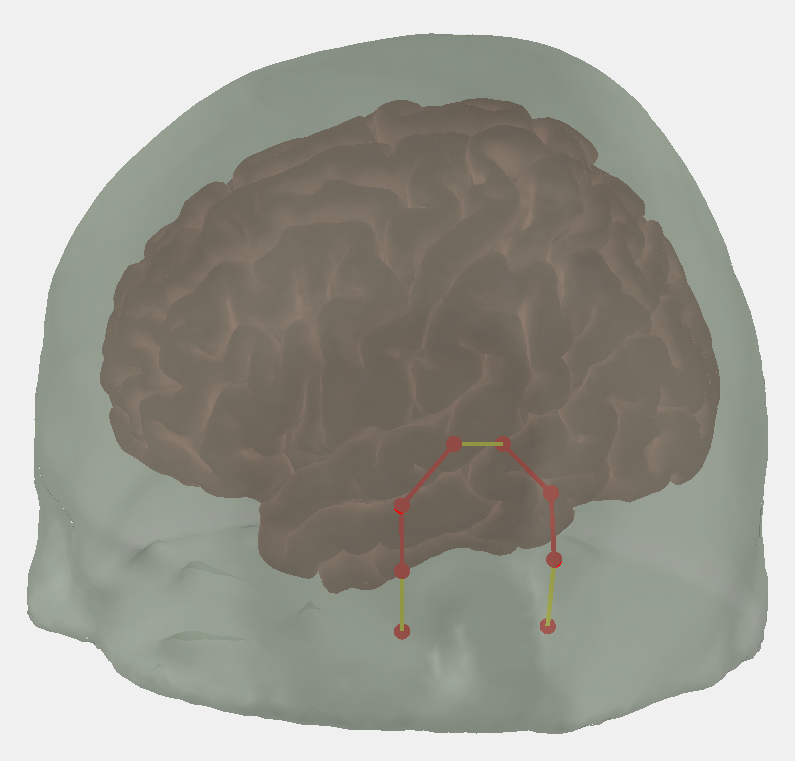
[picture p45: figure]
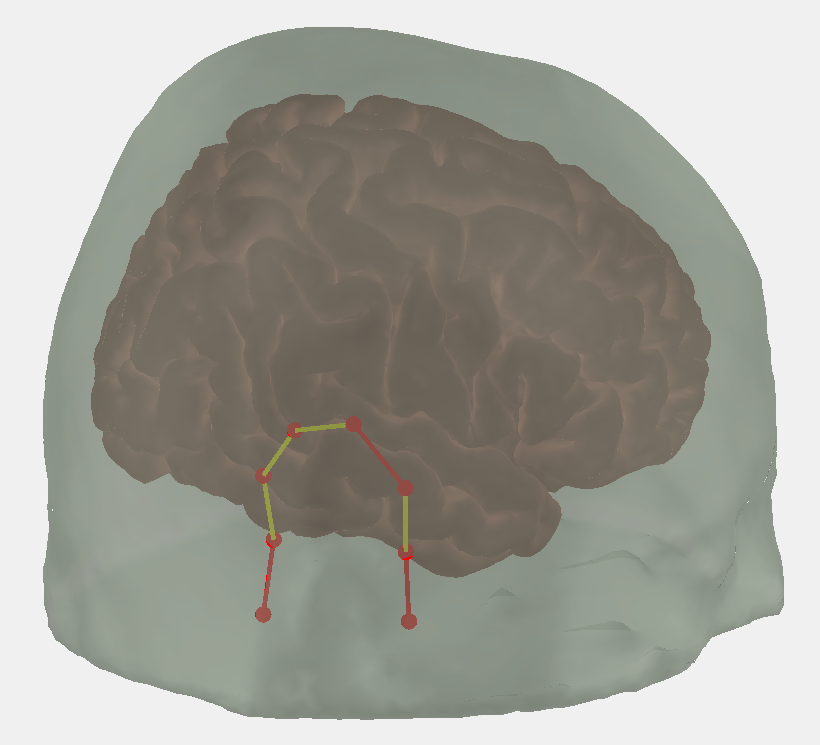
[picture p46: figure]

TPP8

TPP10

TPP10h

TTP8h

RPA

T10h

T8

TP8h

TPP9h

TPP7

TPP9

TP7h

TTP7h

T7

T9h

LPA

L

R

LPA – T9h – T7 – TTP7h – TP7h – TPP7 – TPP9h – TPP9 | TPP10 – TPP10h – TPP8 – TP8h – TTP8h – T8 – T10h – RPA

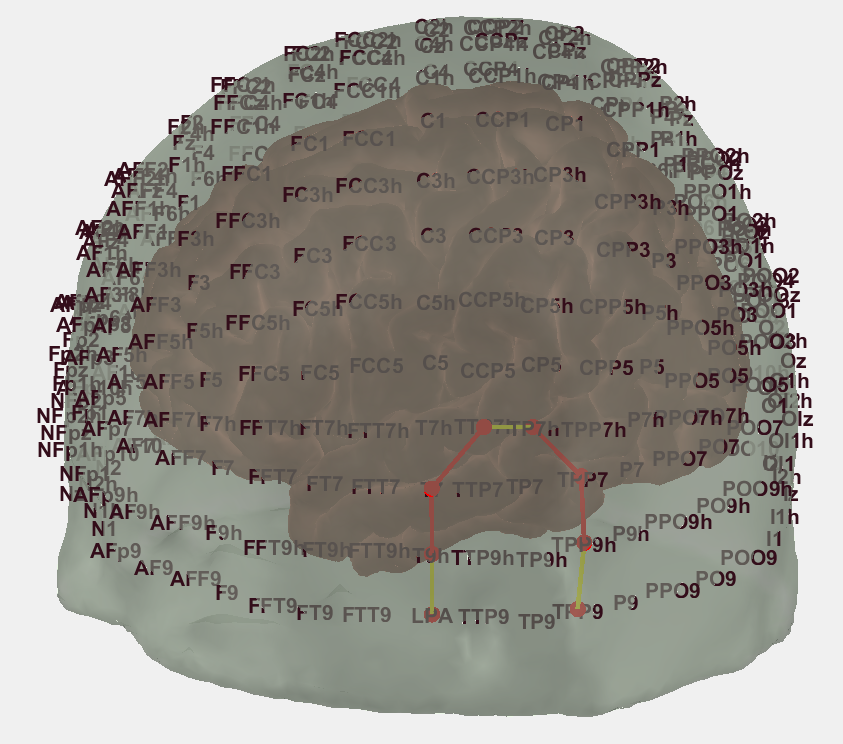
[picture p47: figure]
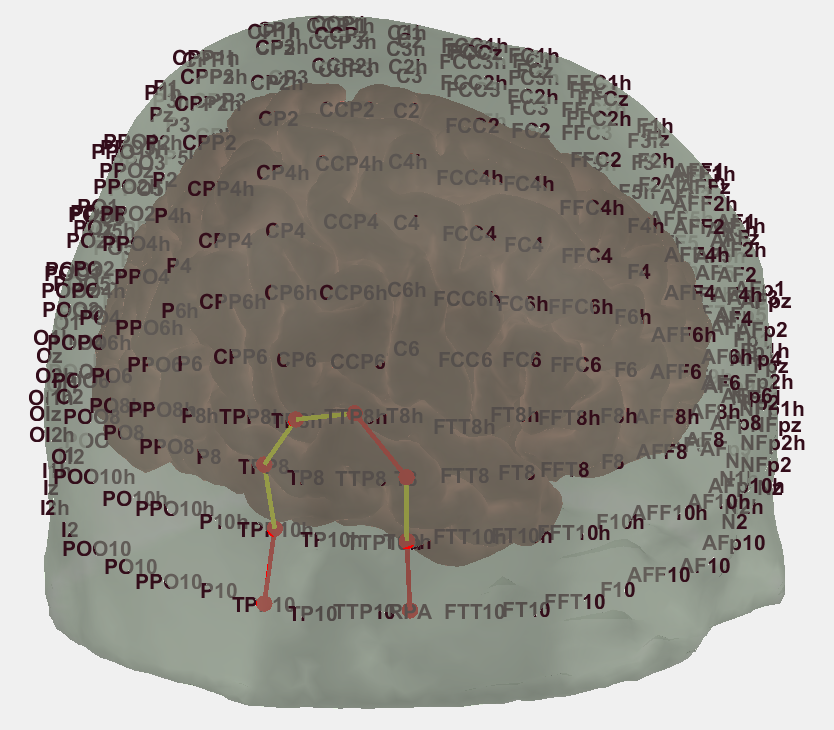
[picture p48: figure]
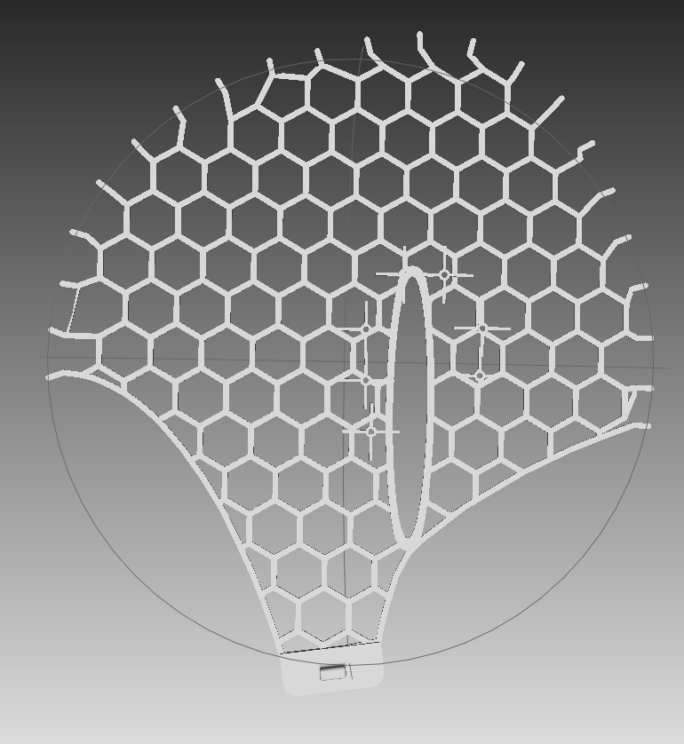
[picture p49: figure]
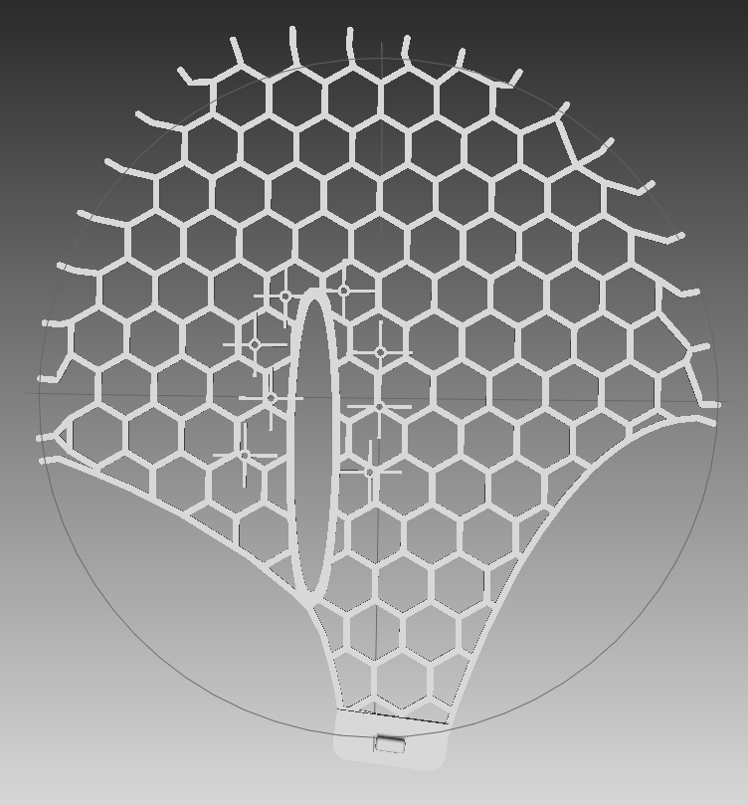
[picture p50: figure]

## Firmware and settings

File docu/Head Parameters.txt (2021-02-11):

Average solution for 56cm HC and both sexes


				Real		Input to Atlas Viewer		AtlasViewer Fit		Input to Atlas Viewer 
						(corrects underfit)		(Head Dimensions)	Uniformly Scaled (x1.09)
Head Circumference (cm)		56.00		57.00				55.7			62.13
Iz to Nz (cm)			35.49		36.4				35.5			39.68
RPA to LPA (cm)			35.68		35.0				35.7			38.15


based on scaled Collin:		Real		Input to Atlas Viewer 		AtlasViewer Fit		Uniformly Scaled (x1.09)
(David prefers this)				(corrects underfit)		(Head Dimensions)	(input)/fit

Head Circumference (cm)		560.0		57.4 cm				560.2			(62.57)/613.0
Iz to Nz (cm)			364.3		37.6 cm				364.8			(40.98)/398.8
RPA to LPA (cm)			351.8		34.2 cm				351.2			(37.28)/385.1

https://upload.wikimedia.org/wikipedia/commons/0/06/AvgHeadSizes.png

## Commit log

2021-02-07 First commit for ninjaCap2
    [chStrap.stl, chinstrap.STL, earslit.stl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]
2021-02-07 update scaling to make circumference as 56cm
2021-02-11 add docu folder
    [Head Parameters.txt]
2021-05-06 load SD file after edited in AtlasViewer
    [grommet.stl, grommetComplement.STL, grommetComplement.stl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]
2023-05-04 update ninjaCap2 to save stl image and few other things
2023-11-28 Fix STL files not floating issue
2024-03-25 update to correct panel deformation
    [grommet.STL, grommetComplement.STL, grommetComplement_not_centered.STL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]
2024-06-10 testing new head model
    [grommet.STL, grommet.stl, grommetComplement.STL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]
2024-11-04 update wrkspace to insert ear slit
    [wrkspace.blend]
2025-07-17 add missing stl files
    [earslitComplement_left.stl, earslitComplement_right.stl, grommet.STL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]
